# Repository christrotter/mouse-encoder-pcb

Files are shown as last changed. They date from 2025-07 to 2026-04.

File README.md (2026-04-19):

# mouse-encoder-pcb
**Update, 2026/04/19:** PCB works perfectly, noise circuit excellent.

Simple standalone mouse-wheel encoder pcb, including a noise filter, but incredibly, no LED.
Designed to be VIK-friendly, and fits ALPS and TTC (and Kailh) encoders (e.g. ALPS EC10E1260502).

## Noise filter
I'd initially struggled with the noise filter on the Ultrafalcon - still getting skipped readings, doubles - but some reading indicated that I needed to change up the resistor values to meet 3.3v spec.  This is the same Bourns-recommended pattern.  

Turns out there are three camps in the noise filter arena... 
1. Only do it in software.
2. Only do it in hardware.
3. Mix of both.
... and if you are in one camp you're 'wrong' to the others.  Anyways, let's give this a shot.

## In use
Note the direction of the modeled FFC cable here...

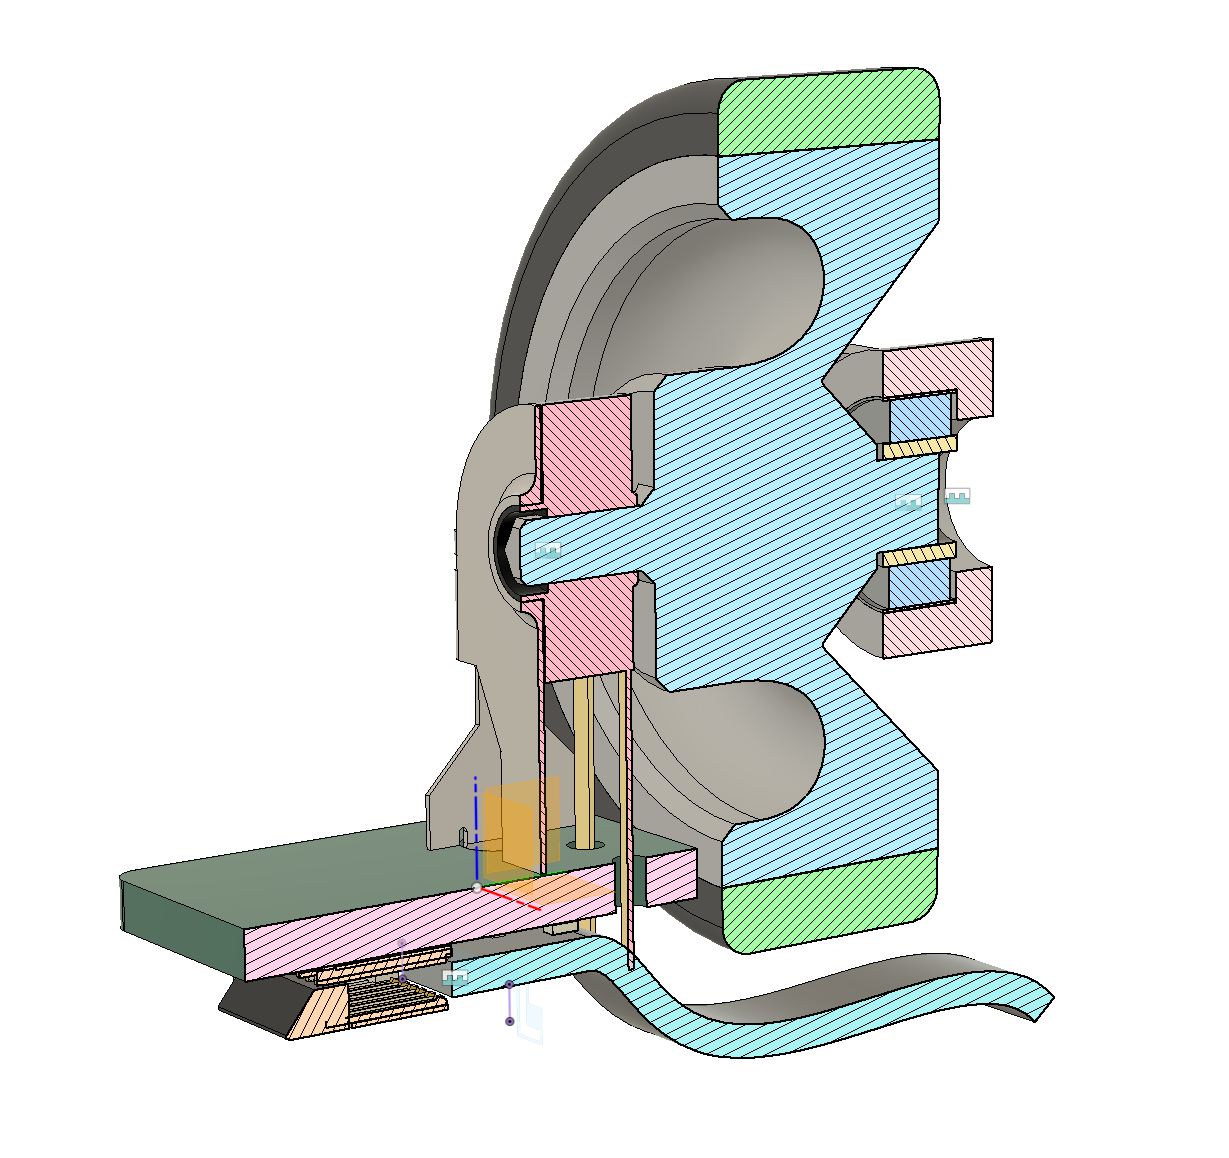
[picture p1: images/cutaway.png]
Cutaway


# PCB render
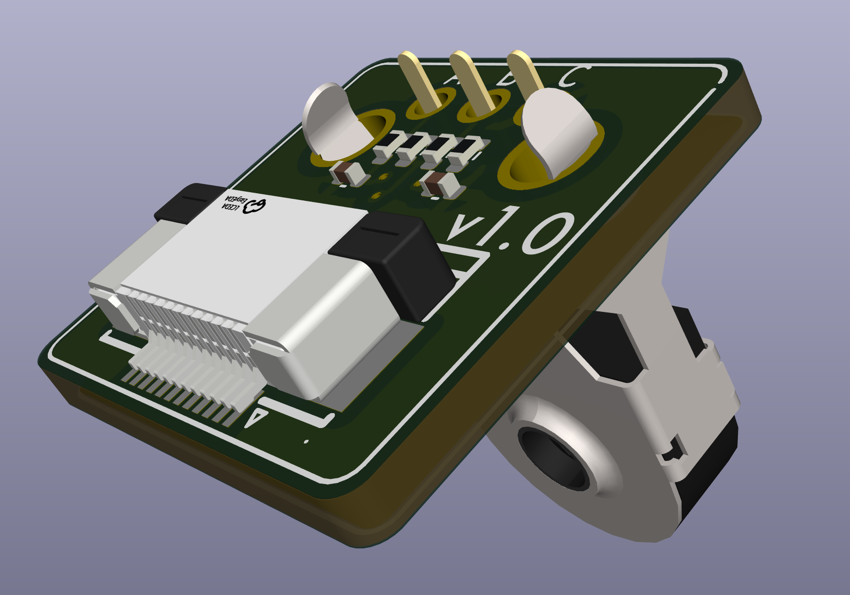
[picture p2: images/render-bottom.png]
Render-bottom

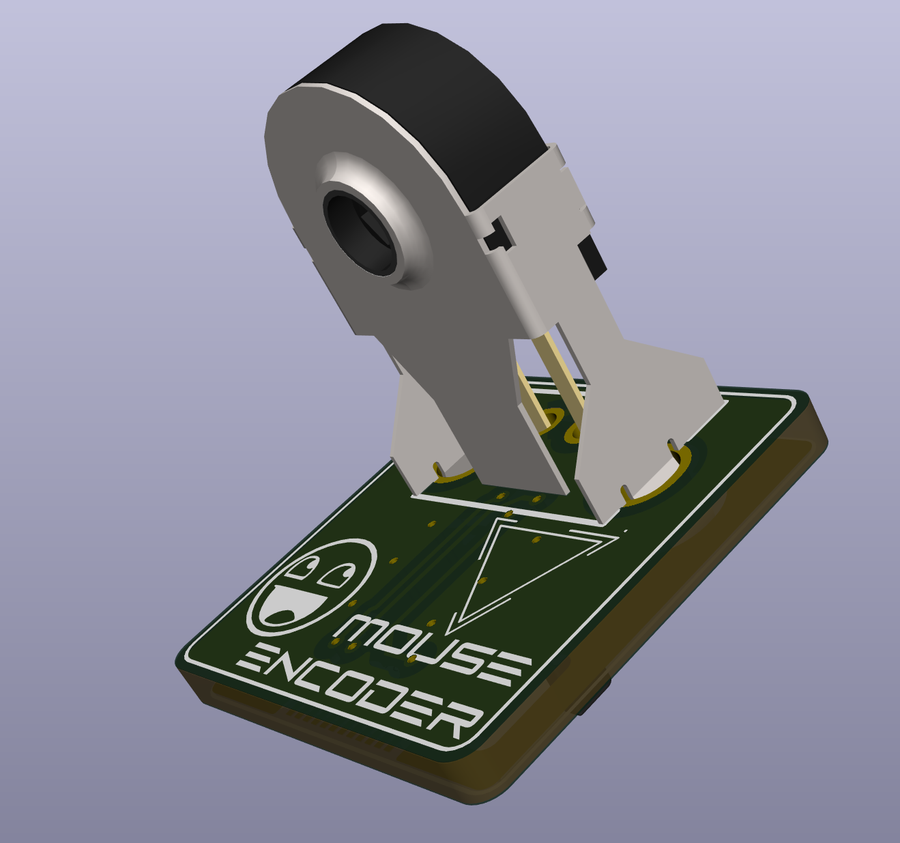
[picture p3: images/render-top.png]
Render-top


# Usage example
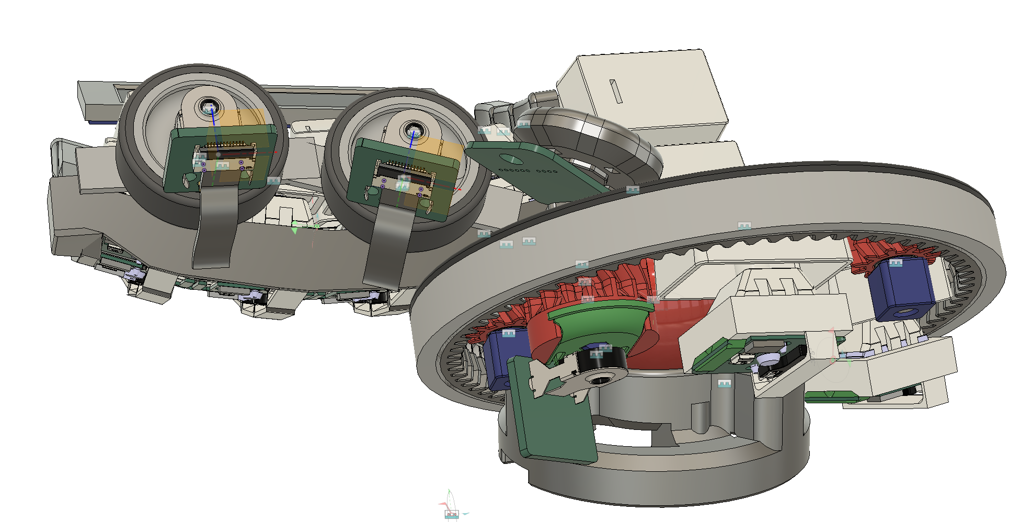
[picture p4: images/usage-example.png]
Usage1

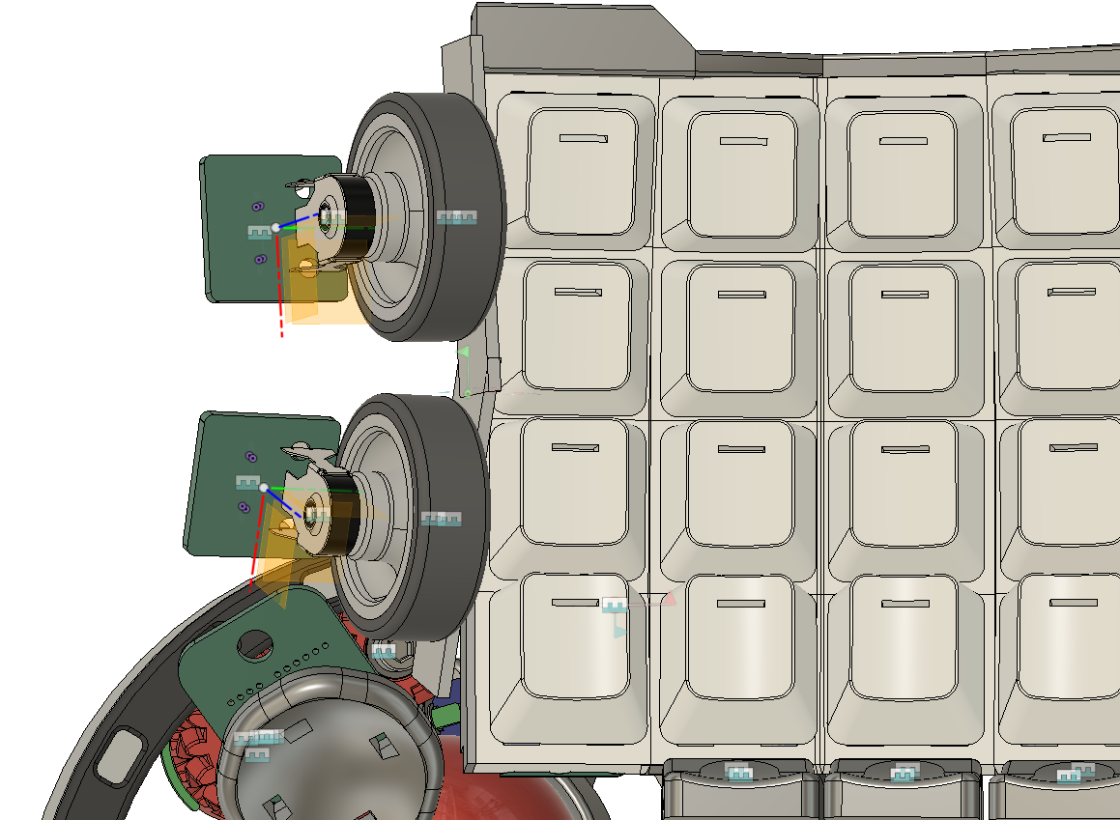
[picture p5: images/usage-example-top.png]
Usage2


# PCB overview
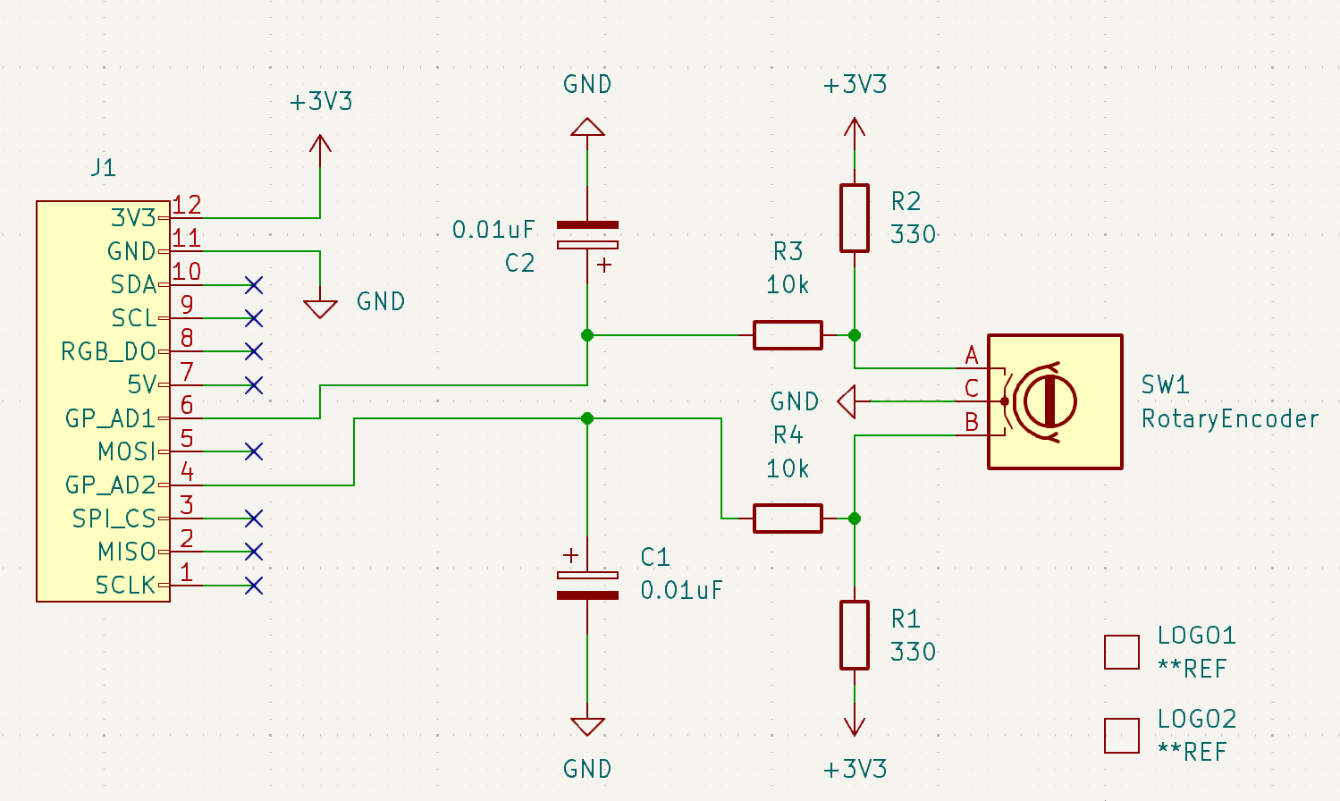
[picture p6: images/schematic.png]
Schematic

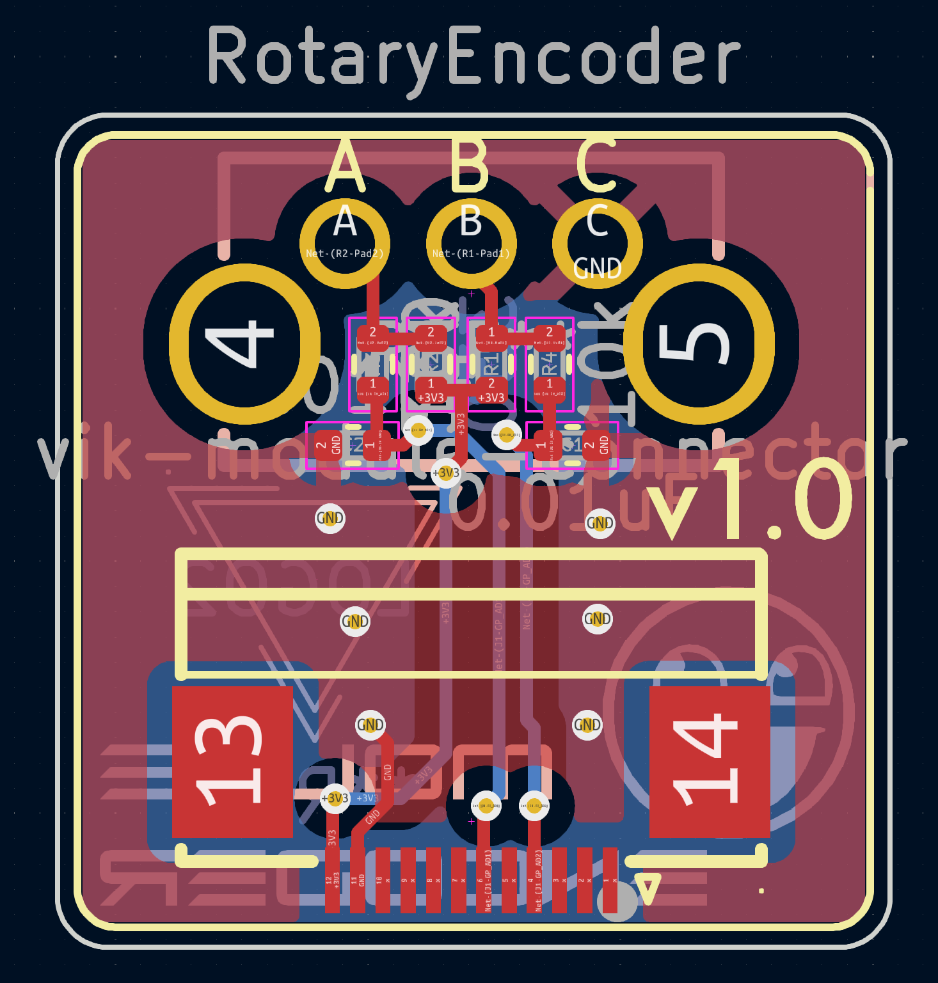
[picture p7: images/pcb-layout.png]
PCB Layout


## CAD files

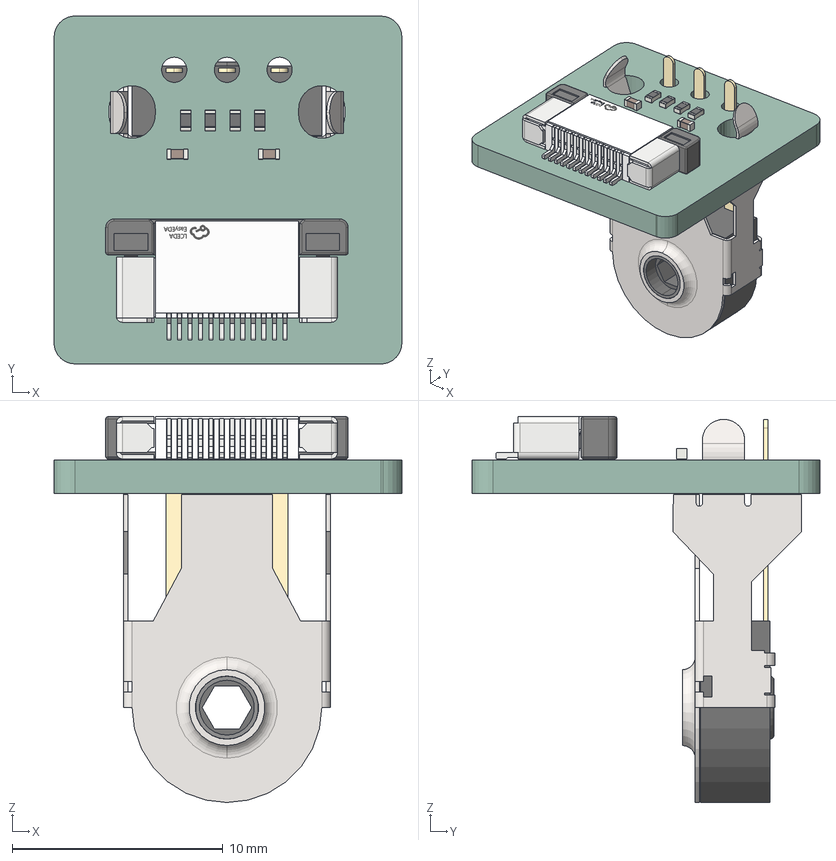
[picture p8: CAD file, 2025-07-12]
mouse-encoder-pcb-v3.step
16.5 x 16.5 x 18.3 mm
R_0402_1005Metric x 4
C_0402_1005Metric x 2
FFC-SMD_FFC05001-12SBA124W5M
SW-TH_EC10EXXXXXXX-L9.8-W6.1-H14.6-P2.5
mouse-encoder-pcb_PCB

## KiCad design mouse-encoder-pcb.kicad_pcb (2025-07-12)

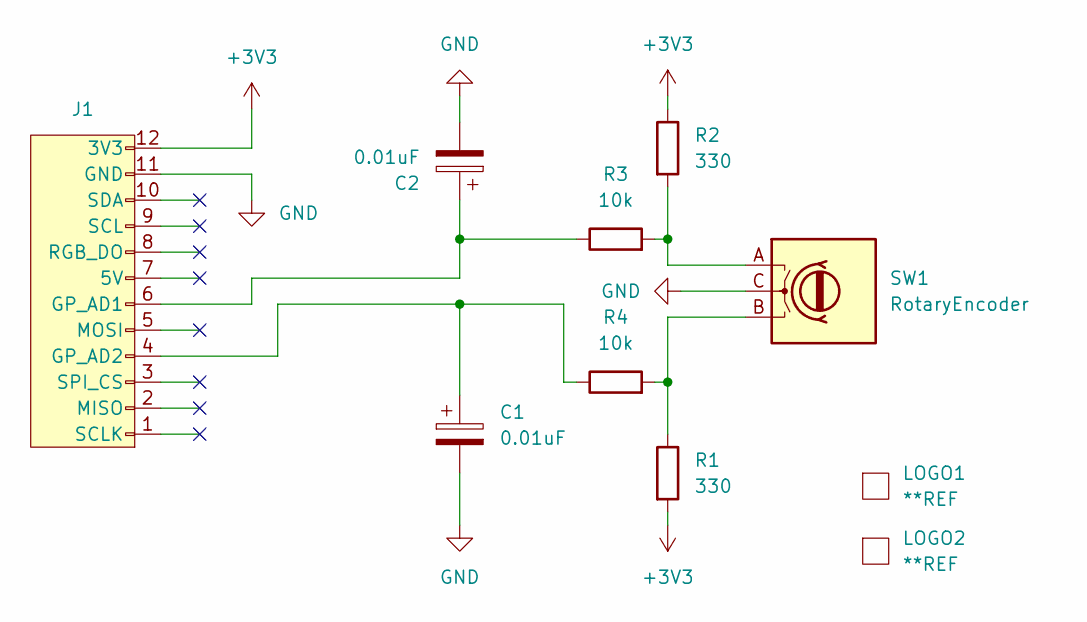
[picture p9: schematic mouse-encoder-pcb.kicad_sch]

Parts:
C1, C2: 0.01uF; C_0402_1005Metric
J1: vik-module-connector; FFC-SMD_FFC05001-12SBA124W5M
LOGO1: **REF; awesome-logo
LOGO2: **REF; vik-logo-small
R1, R2: 330; R_0402_1005Metric
R3, R4: 10k; R_0402_1005Metric
SW1: RotaryEncoder; SW-TH_EC10EXXXXXXX

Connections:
+3V3: J1.12 (3V3), R1.2, R2.1
GND: C1.2, C2.2, J1.11 (GND), SW1.C
unnamed: C2.1, J1.6 (GP_AD1), R3.1
unnamed: C1.1, J1.4 (GP_AD2), R4.1
unnamed: R1.1, R4.2, SW1.B
unnamed: R2.2, R3.2, SW1.A

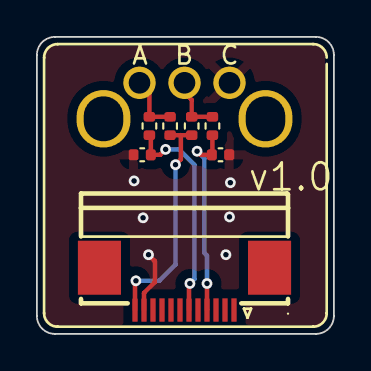
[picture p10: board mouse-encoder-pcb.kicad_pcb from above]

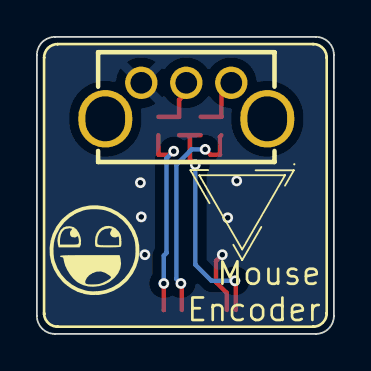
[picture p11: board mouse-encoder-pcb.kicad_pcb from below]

Board: 2 copper layers, 16.5 x 16.5 mm, 10 parts (3 on the bottom side), 6 nets.

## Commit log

2025-06-30 adding first rev
    [mouse-encoder-pcb.kicad_pcb, mouse-encoder-pcb.kicad_sch]
2025-06-30 forgot to clear a ref
    [mouse-encoder-pcb.kicad_pcb]
2025-07-01 working square version
    [mouse-encoder-pcb.kicad_pcb, mouse-encoder-pcb.kicad_sch]
2025-07-12 adding step
    [mouse-encoder-pcb-v3.step]
2025-07-12 updating footprints
    [mouse-encoder-pcb.kicad_pcb, mouse-encoder-pcb.kicad_sch]
